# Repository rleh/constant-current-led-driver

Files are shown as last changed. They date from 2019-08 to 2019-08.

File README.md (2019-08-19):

# Constant Current LED Driver

*WORK IN PROGRESS!*

Goal of this project is to design a constant current LED driver for high power LED modules.
To be able to use large LED modules (e.g. V_FW = 35V) or multiple modules in series boost topology is used.
The maximum output voltage is configurable up to 70V to allow two 35V modules in series.

TIs [LM3424](http://www.ti.com/lit/ds/symlink/lm3424.pdf) chip is used in this design.

The current is adjustable, 827mA for the LED module [*Nichia NFCLJ108B-V1*](www.fairchip.com/pdf/Nichia/NFCLJ108B-V1.pdf)
and 389mA for [*Nichia NFCLL060B-V1*](https://lumstatic.com/Ke/DG/JkgO4GaB6Fu6ut0LEA.pdf) are testet.

To adjust the LED brightness a PWM input is available, that can be used for strobe light too.
Additionally multiple driver modules can be syncronized using the SYNC input.

In order to protect the LED from thermal destruction, the current is reduced from a temperature of 70°C until it is switched off at approx. 90°C (thermal foldback).
For this purpose an NTC (Vishay NTCLE100E3104JB0) can be attached to the LED.
If this feature is not required, a 100kΩ must be soldered in instead of the NTC.

Any 18V..20V (cheap) notebook power supply with a sufficient power rating can be used as an AC adapter.

## LED Driver PCB

### Specs
* Input: 12V to 24V
* Output: Up to 20 LEDs (70V) at 827mA or 389mA
* 70°C - 90°C Thermal Foldback
* 1.5MHz Switching Frequency
* PWM Dimming up to 30 kHz (?)

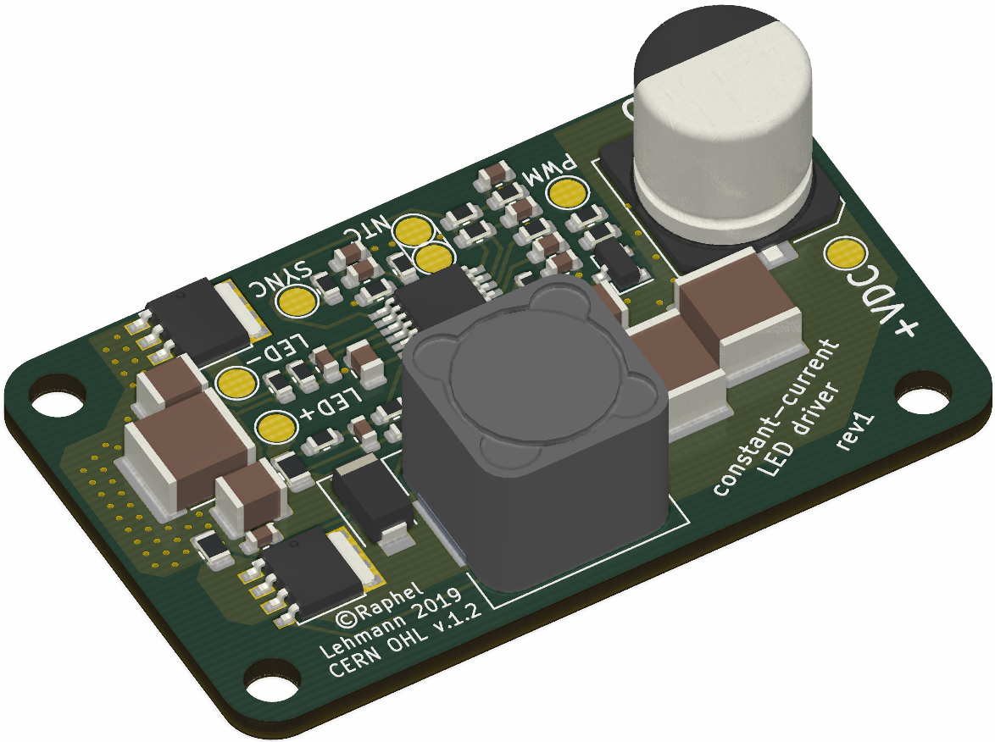
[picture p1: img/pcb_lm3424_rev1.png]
PCB Preview


### Parts

| Designator | Part | MPN | Quantity | Prize@1 | Prize@10 |
| --- | --- | --- | --- | --- | --- |
| U1 | LM3424 | LM3424MHX | 1 | 2.73$ | 2.45$ |
| Q2,Q3 | PSMN025-80YLX | PSMN025-80YLX | 2 | 0.57$ | 0.51$ |
| L1 | WE-PD 7447709220 | 7447709220 | 1 | 2.41$ | 2.20$ |
| L1 | **or** MSS1210-153ME | MSS1210-153ME | 1 | 2.19€ | 1.96€ |
| D1 | VSSAF5M10-M3/H | VSSAF5M10-M3/H | 1 | 0.45$ | 0.36$ |
| D1 | **or** SL510AFL-TP | SL510AFL-TP | 1 | 0.54$ | 0.46$ |
| Q1 | 2N7002 | T2N7002AK,LM | 1 | 0.15$ | 0.13$ |
| NTC | NTCLE100E3104JB0 | NTCLE100E3104JB0 | 1 | 0.69$ | 0.57$ |
| C4 | EEH-ZC1K470P | EEH-ZC1K470P | 1 | 2.14$ | 1.72$ |
| C1,C12,C13 | 4.7µF, 100V, X7R, 1210 | C1210X475K101T | 3 | 0.41$ | 0.30$ |
| C2,C3,C14  | 10µF, 100V, X7R, 2220  | FS55X106K101EHG | 3 | 0.47$ | 0.35$ |
| R15 | 100mΩ, 0805, 1W | RUT2012FR100CS | 1 | 0.30$ | 0.26$ |
| R13 | 60mΩ, 0805, 1W | RLP73M2AR062FTDF | 1 | 0.52$ | 0.45$ |
| other R | 8 distinct values | MPN | 17 | 0.05$ | 0.01$ |
| other C | 5 distinct values | MPN | 10 | 0.10$ | 0.02$ |

**Total Cost**: approx. 14$ @ 1pcs; <12$ @ 10pcs

## License

Copyright Raphael Lehmann 2019

Licensed under CERN OHL Version 1.2

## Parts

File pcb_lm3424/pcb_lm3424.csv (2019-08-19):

ID | Bezeichner | Gehäuse | Stückzahl | Bezeichnung | Anbieter und Referenz
1 | U1 | ETSSOP-20-1EP_4.4x6.5mm_P0.65mm_EP3x4.2mm | 1 | LM3424
2 | J8 | TestPoint_Pad_D2.0mm | 1 | –
3 | J7 | TestPoint_Pad_D2.0mm | 1 | +
4 | J6,J5 | TestPoint_Pad_D2.0mm | 2 | NTC
5 | J4 | TestPoint_Pad_D2.0mm | 1 | GND
6 | J3 | TestPoint_Pad_D2.0mm | 1 | SYNC
7 | J2 | TestPoint_Pad_D2.0mm | 1 | VIN
8 | J1 | TestPoint_Pad_D2.0mm | 1 | PWM
9 | R19,R14,R1 | R_0603_1608Metric | 3 | 0
10 | H3,H2,H1 | MountingHole_3.2mm_M3 | 3 | M3
11 | R18 | R_0603_1608Metric | 1 | 150
12 | C18,C17 | C_0603_1608Metric | 2 | 100p
13 | L1 | L_12x12mm_H8mm | 1 | MSS1210-104KE
14 | C14 | C_2220_5650Metric | 1 | COUT
15 | C13,C12 | C_1210_3225Metric | 2 | COUT
16 | C11,C16,C8,C5 | C_0603_1608Metric | 4 | 100n
17 | C3,C2 | C_2220_5650Metric | 2 | CIN
18 | C1 | C_1210_3225Metric | 1 | CIN
19 | R17,R3 | R_0603_1608Metric | 2 | 1k8
20 | R16 | R_0603_1608Metric | 1 | 120k
21 | R15 | R_0805_2012Metric | 1 | 100m 1W
22 | R13 | R_0805_2012Metric | 1 | 60m 1W
23 | R12,R8,R7,R4 | R_0603_1608Metric | 4 | 15k
24 | R11,R2 | R_0603_1608Metric | 2 | 10k
25 | R10,R9 | R_0603_1608Metric | 2 | 1k|470
26 | R6,R5 | R_0603_1608Metric | 2 | 4k7
27 | Q3,Q2 | LFPAK56 | 2 | PSMN025-80YLX
28 | Q1 | SOT-23 | 1 | 2N7002
29 | D1 | D_SMA | 1 | VSSAF5M10-M3/H (DO-221AC)
30 | C15 | C_0603_1608Metric | 1 | 47p
31 | C10 | C_0603_1608Metric | 1 | DNP
32 | C9 | C_0805_2012Metric | 1 | 2µ2 X7R 16V 0805
33 | C7,C6 | C_0603_1608Metric | 2 | 270n
34 | C4 | CP_Elec_10x10.5 | 1 | CIN

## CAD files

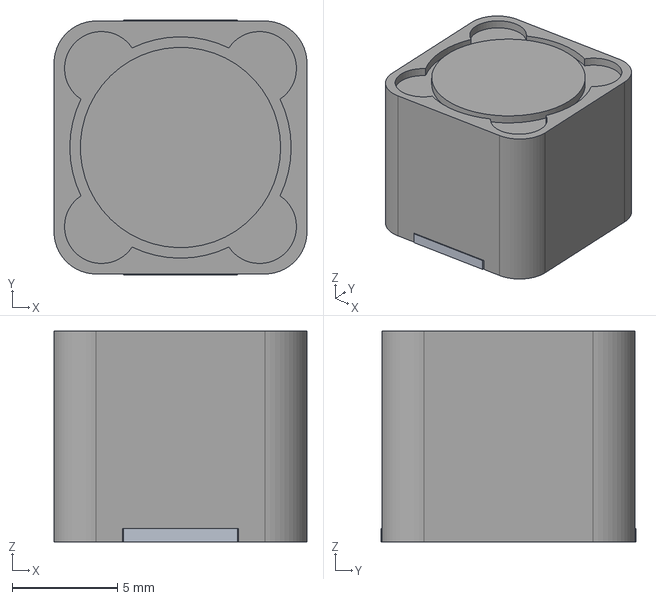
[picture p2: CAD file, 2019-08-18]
pcb_lib/Inductor_Coilcraft_MSS1210.stp
12.0 x 12.1 x 10.0 mm

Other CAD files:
pcb_lib/Inductor_Coilcraft_MSS1210.FCStd

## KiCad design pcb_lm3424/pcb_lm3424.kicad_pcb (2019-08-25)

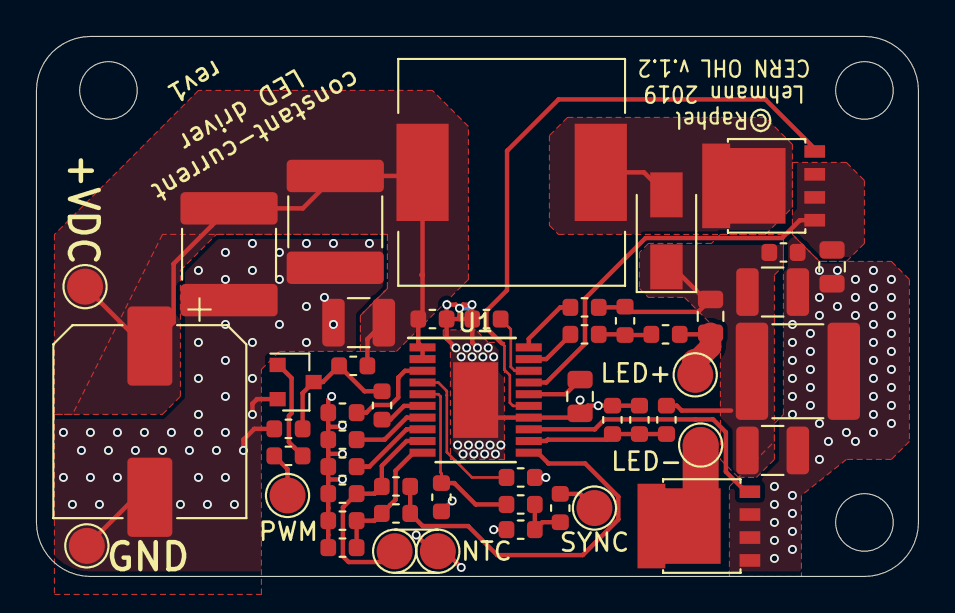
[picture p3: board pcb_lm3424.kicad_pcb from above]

Board: 2 copper layers, 49.0 x 30.0 mm, 54 parts (0 on the bottom side), 29 nets.

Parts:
C1: CIN; C_1210_3225Metric
C2, C3: CIN; C_2220_5650Metric
C4: CIN; CP_Elec_10x10.5
C5, C8, C11, C16: 100n; C_0603_1608Metric
C6, C7: 270n; C_0603_1608Metric
C9: 2µ2 X7R 16V 0805; C_0805_2012Metric
C10: DNP; C_0603_1608Metric
C12, C13: COUT; C_1210_3225Metric
C14: COUT; C_2220_5650Metric
C15: 47p; C_0603_1608Metric
C17, C18: 100p; C_0603_1608Metric
D1: VSSAF5M10-M3/H (DO-221AC); D_SMA
H1, H2, H3: M3; MountingHole_3.2mm_M3
J1: PWM; TestPoint_Pad_D2.0mm
J2: VIN; TestPoint_Pad_D2.0mm
J3: SYNC; TestPoint_Pad_D2.0mm
J4: GND; TestPoint_Pad_D2.0mm
J5, J6: NTC; TestPoint_Pad_D2.0mm
J7: +; TestPoint_Pad_D2.0mm
J8: –; TestPoint_Pad_D2.0mm
L1: MSS1210-104KE; L_12x12mm_H8mm
Q1: 2N7002; SOT-23
Q2, Q3: PSMN025-80YLX; LFPAK56
R1, R14, R19: 0; R_0603_1608Metric
R2, R11: 10k; R_0603_1608Metric
R3, R17: 1k8; R_0603_1608Metric
R4, R7, R8, R12: 15k; R_0603_1608Metric
R5, R6: 4k7; R_0603_1608Metric
R9, R10: 1k|470; R_0603_1608Metric
R13: 60m 1W; R_0805_2012Metric
R15: 100m 1W; R_0805_2012Metric
R16: 120k; R_0603_1608Metric
R18: 150; R_0603_1608Metric
U1: LM3424; ETSSOP-20-1EP_4.4x6.5mm_P0.65mm_EP3x4.2mm

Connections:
+VDC: C1.1, C2.1, C3.1, C4.1, C16.1, J2.1, L1.1, R2.1, U1.1, U1.2
/PWM: J1.1, R1.2
/VCC: C9.2, U1.16
/nDIM: Q1.3, R2.2, R3.1, R19.2
GND: C1.2, C2.2, C3.2, C4.2, C5.2, C6.2, C7.2, C8.2, C9.1, C11.2, C12.2, C13.2, C14.2, C15.2, C16.2, C17.2, J4.1, J6.1, Q1.2, Q3.1, Q3.2, Q3.3, R3.2, R4.2, R5.2, R6.2, R7.2, R11.1, R13.2, R17.2, U1.14, U1.21
unnamed: C5.1, U1.3
unnamed: C6.1, U1.7
unnamed: C7.1, R7.1, R8.2, U1.10
unnamed: C8.1, J5.1, R12.2, U1.9
unnamed: C10.1, C11.1, C12.1, C13.1, C14.1, D1.1, R9.1, R15.1, R16.1
unnamed: C10.2, R10.1, R14.2
unnamed: C15.1, R16.2, R17.1, U1.12
unnamed: C17.1, C18.1, R18.1
unnamed: C18.2, R5.1, U1.5
unnamed: D1.2, L1.2, Q2.5
unnamed: J3.1, R18.2
unnamed: J7.1, R14.1, R15.2
unnamed: J8.1, Q3.5
unnamed: Q1.1, R1.1
unnamed: Q2.1, Q2.2, Q2.3, R13.1, U1.17
unnamed: Q2.4, U1.15
unnamed: Q3.4, U1.13
unnamed: R4.1, U1.4
unnamed: R6.1, U1.8
unnamed: R9.2, U1.20
unnamed: R10.2, U1.19
unnamed: R11.2, U1.18
unnamed: R8.1, R12.1, U1.11
unnamed: R19.1, U1.6

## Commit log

2019-08-18 Lib: add MSS1210 3d model
    [Inductor_Coilcraft_MSS1210.FCStd, Inductor_Coilcraft_MSS1210.stp]
2019-08-18 Add PCB schematic
    [pcb_lm3424.sch]
2019-08-18 Add PCB layout
    [pcb_lm3424.kicad_pcb]
2019-08-19 Change inductor
    [pcb_lm3424.sch]
2019-08-19 Add BOM
    [pcb_lm3424.csv]
2019-08-25 Gerber settings
    [pcb_lm3424.kicad_pcb]
2019-08-26 Add panel with 4 PCBs
    [pcb_lm3424_4x.kicad_pcb]

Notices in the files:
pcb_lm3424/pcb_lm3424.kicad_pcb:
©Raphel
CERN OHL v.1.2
